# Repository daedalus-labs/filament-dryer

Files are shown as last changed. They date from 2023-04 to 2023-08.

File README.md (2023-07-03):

# MQTT Filament Dryer

This project is Raspberry Pi Pico-based dryer for Filament for use with 3D Printers that provides feedback and command/control through MQTT.

This project does not have any external dependencies, but does require the [Pico C/C++ SDK](https://www.raspberrypi.com/documentation/microcontrollers/c_sdk.html#sdk-setup)
to build. The [picotool](https://github.com/raspberrypi/picotool) project is required for installing configuration data.

## Build

In order to build, the `PICO_SDK_PATH` environment variable must be set. Once that is set, the `build.bash` script provides
a single command build interface, which will build using all default build options:

```bash
./build.bash --build
```

The `build.bash` script will forward CMake args, so build options can be modified using `-D{OPTION}={VALUE}`. For
example, the command below will build this project with such that the temperature sensor will read data from `GP12`.

```bash
./build.bash --build -DDHT_DATA_PIN=12
```

### Available Build Options

| Option | Default Value | Description |
| --- | --- | --- |
| MQTT_PORT | 1883 | The TCP/IP Port to use for MQTT communication |
| DHT_FEEDBACK_PIN | 254 | The GPIO pin of the DHT Feedback LED. The LED will be `ON` when reading data, `OFF` otherwise |
| DHT_DATA_PIN | 17 | The GPIO pin of the DHT Temperature Sensor. |
| HEATER_FEEDBACK_PIN | 15 | The GPIO pin of the Heater Feedback LED. It is `ON` when the heater is on, `OFF` otherwise |
| HEATER_CONTROL_PIN  | 19 | The GPIO pin of the Heater Relay. |
| SYSTEM_LED_PIN | 13 | The GPIO pin of the System LED. It is `ON` when the Pico has booted and is running, `OFF` otherwise  |
| MQTT_FEEDBACK_PIN | 14 | The GPIO pin of the MQTT Feedback LED. It is `ON` when connected to the MQTT broker, `OFF` otherwise |

The LED behaviors of `DHT_FEEDBACK_PIN`, `SYSTEM_LED_PIN`, `MQTT_FEEDBACK_PIN`, and `HEATER_FEEDBACK_PIN` can all be disabled by setting that value
to a value larger than `NUM_BANK0_GPIOS`. A default value of `254` means that LED is not used by default.

### Cleaning

The `build.bash` script also provides an option to clean out all build artifacts via `--clean`:

```bash
./build.bash --clean
```

## Installation

After building the project, the `filament-dryer.uf2` file can be copied to the Pico as described in the [fine manuals for the Pico](https://www.raspberrypi.com/documentation/microcontrollers/c_sdk.html#your-first-binaries).

Additional documentation on wiring setup and a pre-designed enclosure is available [here](docs/README.md).

### Configuration

Configuration data is loaded onto the Raspberry Pi at run-time using the `load.py` script, which will encode the data into
a binary blob and load in the Pico's flash. The Pico should be hooked up to the computer before running the script.

```bash
./load.py --ssid MyAwesomeWifi --passphrase DontHackMyNetwork --device daryl --broker wilson
```

| Option | Description |
| --- | --- |
| `--ssid` or `-s` | The SSID of the Wireless Network to use for MQTT communication |
| `--passphrase` or `-p` | The passphrase of the Wireless network |
| `--device` or `-d` | The device name to use for MQTT communication |
| `--broker` or `-b` | The hostname or IP address of the MQTT Broker to use |

### Monitoring via MQTT

The dryer publishes a collection fo MQTT topics for monitoring the status of the dryer. All topics are relative
to the device name (i.e. if the device is named `daryl`, the container humidity will be available on `daryl/container/humidity`).

| Topic | Description | Data Type |
| --- | --- | --- |
| `container/humidity` | The current humidity within the container, as a percentage. | Float |
| `container/temperature` | The current temperature within the container, in degrees Celsius. | Float |
| `container/target_temperature` | The desired temperature within the container, in degrees Celsius. | Float |
| `container/heater` | The current state of the heater. Will be "on" if it is on, "off" otherwise. | String |

The dryer subscribes to the following MQTT topics for command/control of the dryer:

| Topic | Description | Data Type |
| --- | --- | --- |
| `container/target_temperature/set` | Sets the desired temperature within the container, in degrees Celsius. | Float |

Finally, there are some MQTT topics that provide metadata on the device status:

| Topic | Description | Data Type |
| --- | --- | --- |
| `board/temperature` | The current temperature of the Pico, in degrees Celsius. | Float |
| `version` | The version of software running on the Pico. | String |
| `uid` | The UID of the Pico. | String |

It should be noted that the MQTT interface will require all data be encoded as a string; the `Data Type` column above

## Credits and Thanks

* [Hermann-SW](https://gist.github.com/Hermann-SW) for sharing guides on how to use the Raspberry Pi Pico's flash memory on the [Raspberry Pi Forums](https://forums.raspberrypi.com//viewtopic.php?f=145&t=300146).
* [Erich Styger](https://github.com/ErichStyger) for a really great breakdown of using [MQTT in the lwIP stack](https://mcuoneclipse.com/2023/02/11/using-mqtt-with-the-raspberry-pi-pico-w-and-homeassistant-for-an-optimized-solar-energy-electrical-vehicle-charger/).

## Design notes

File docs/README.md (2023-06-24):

# Building the Filament Dryer

This project will make use of an existing dryer box. [This one](https://www.thingiverse.com/thing:2953325) is recommended, but
any dryer box that can support a heater and temperature sensor will work.

## Necessary Hardware

Once the dryer box is assembled, the following hardware is needed to assembly the controller:

* A [Raspberry Pi Pico W or WH](https://www.raspberrypi.com/products/raspberry-pi-pico/?variant=raspberry-pi-pico-w).
* A prototype PCB large enough to support the Pico.
  * The enclosure was designed around the [ElectroCookie Prototype PCB](https://www.amazon.com/dp/B07ZYNWJ1S).
* A 5V Relay capable of supporting the Heater.
  * The enclosure was designed around this [HiLetgo](https://www.amazon.com/dp/B00LW15A4W) relay.
* An AC-to-DC Power Module capable of providing 5V at 1A or greater.
  * The enclosure was designed around this [NOYITO](https://www.amazon.com/dp/B07C1XCH68) power module.
* A DHT-22/AM-2302 Temperature sensor.
  * [HiLetgo](https://www.amazon.com/dp/B0795F19W6) offers one already wired and ready to go.
* A heating pad for a terrarium or reptile enclosure.
  * This one from [BN-LINK](https://www.amazon.com/dp/B08C93ZGPJ) is a cheap and effective option.
* A desiccant for drying the air.
  * [Slice Engineering](https://www.amazon.com/dp/B09BVYYD7B) makes one specifically for filament.

Assembly will also require basic electrical components, such as wires, LEDs, resistors, diodes, header pins, solder, and
[splicing connectors](https://www.amazon.com/dp/B08W3QXN9B), as well as [grommets](https://www.amazon.com/dp/B09MT34X2B)
to help seal the holes drilled in the enclosure.

## Wiring and Assembly

Most of the components, such as the relay and power module, will be ready to go out of the box and need only be
dropped into the enclosure and wired to the Pico PCB. They can be set aside until the Pico PCB is ready.

### Setting up the Pico PCB

Although any PCB software can be used to create a custom PCB, the wiring here is simple enough that using a Prototyping
PCB is fairly straight forward. Simply solder on headers as shown below:

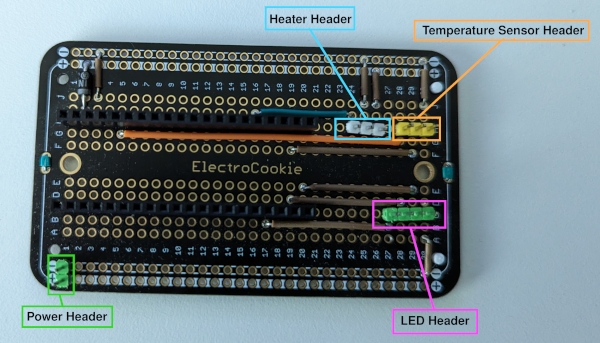
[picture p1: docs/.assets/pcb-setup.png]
Header Diagram


If using the default build options, the headers will be wired as shown in [this diagram](.assets/pcb.png). The setup
used here powers the Pico through VSYS, which requires a schottky diode (D1), a 1N5817 in the linked diagram, in order
to protect the system when using a USB to monitor or reprogram the device.

Once all the headers are soldered in place, the Pico PCB should look something like this:

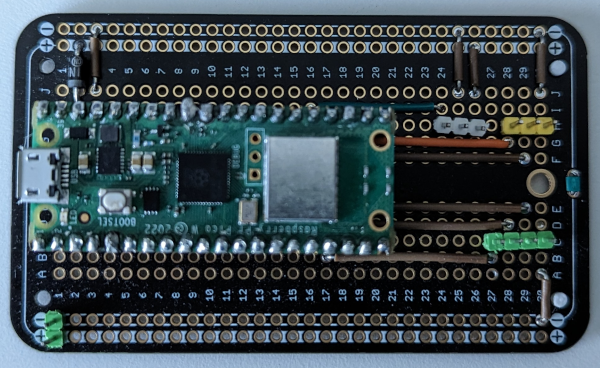
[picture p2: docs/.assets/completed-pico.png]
Pico PCB


It is possible to use a different setup if it is not possible to get a Pico WH or solder on headers, as long as the
connections match the provided wiring diagram (or whatever the build options specify).

### Enclosure

The enclosure comes in two pieces: The enclosure base and a lid. The STL files are available in the `stl` folder, and can
be imported into something like [Cura](https://ultimaker.com/software/ultimaker-cura/) or [Slic3r](https://slic3r.org/)
for use with 3D Printers.

It has been designed with the intention of not requiring supports to print, with a lid that allows easy access to the internal
components should anything need to be updated in the future. This is a filament dryer, so the goal of the lid is primarily
to prevent incidental contact with the internal parts.

The sensor and heater can come in through the large hole in the front of the enclosure, which can optionally be sealed with
a grommet if desired. There is also 3 small holes up front designed for 5mm LEDs, which by default are used to indicate when
the Heater is on/off, MQTT is connected, and the system is on.

Once the enclosure has been printed and the Pico PCB assembled, the components should all drop in:

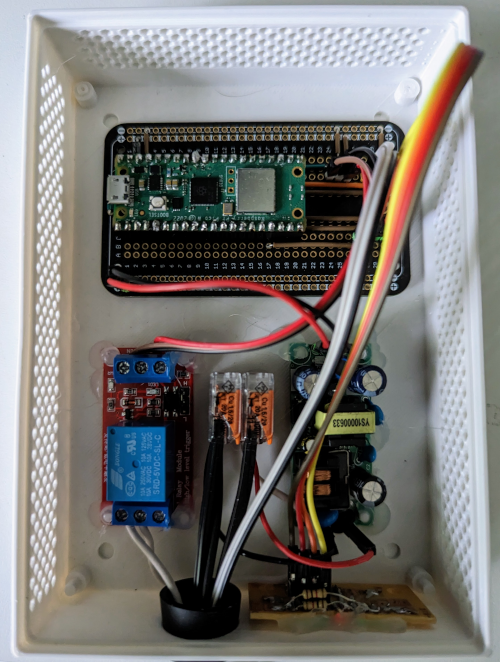
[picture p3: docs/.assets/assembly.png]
Full Assembly


#### Modifying the Enclosure

The CAD models for the enclosure are provided in the `cad` folder. They can be modified using [FreeCAD](https://www.freecad.org/).

### Connecting the Heater

Connecting the Heater only requires cutting off the AC plug it comes with and connecting it to the Power Relay using the
splicing connecters as shown below:

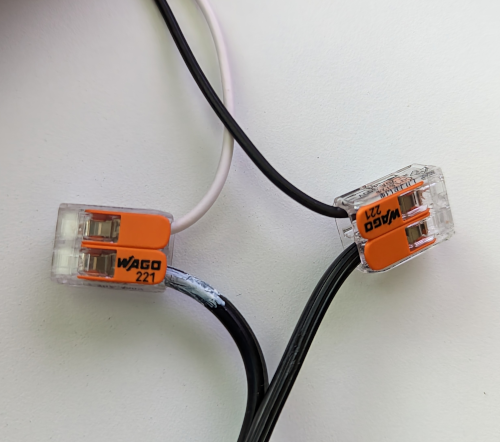
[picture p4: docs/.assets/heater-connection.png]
Heater Connecting


### Putting it all together

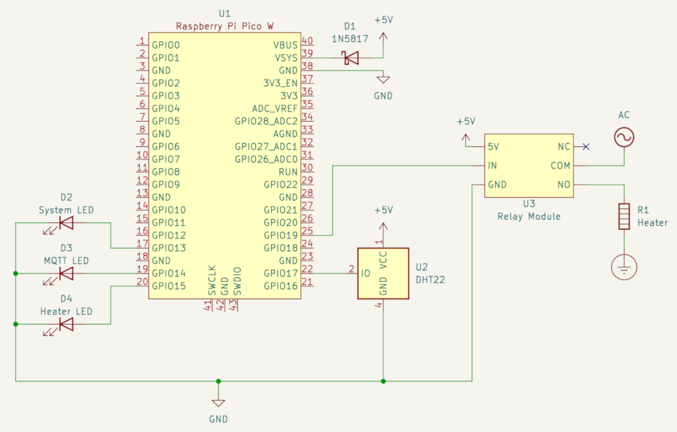
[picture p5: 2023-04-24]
docs/.assets/pcb.png

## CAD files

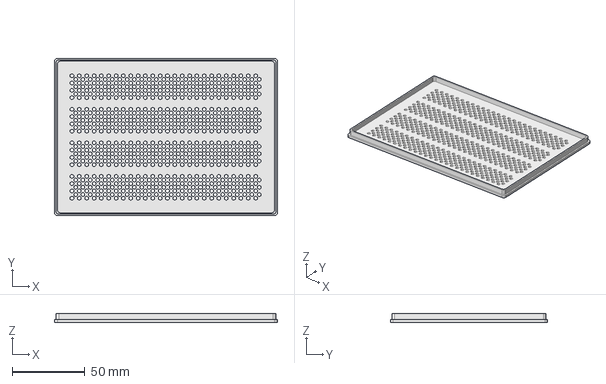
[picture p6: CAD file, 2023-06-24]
docs/cad/enclosure-lid-no-pegs.FCStd
153.0 x 108.0 x 6.00 mm

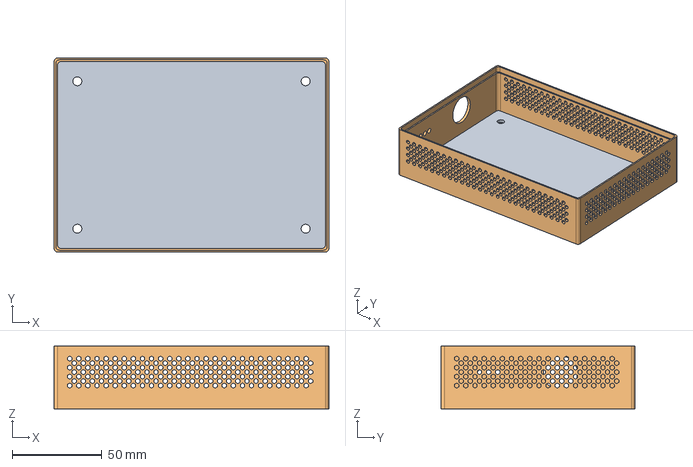
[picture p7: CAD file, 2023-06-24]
docs/cad/enclosure-no-pegs.FCStd
153.0 x 108.0 x 35.0 mm
Enclosure Base
Enclosure Walls

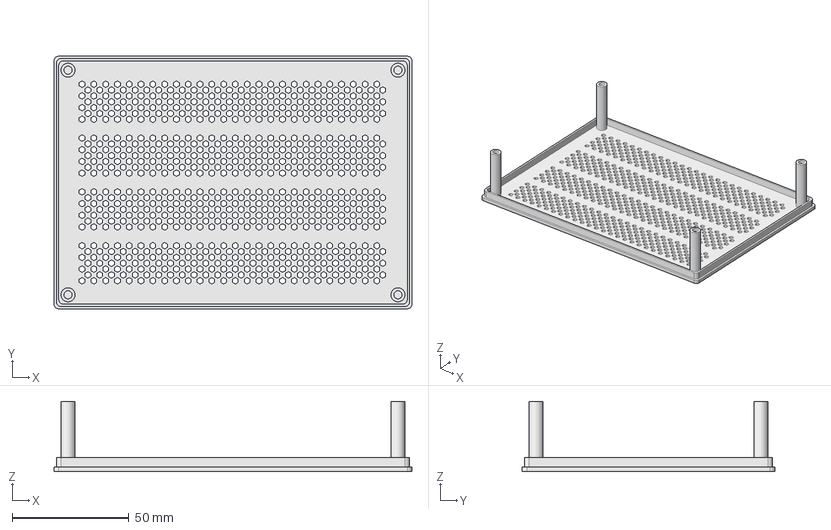
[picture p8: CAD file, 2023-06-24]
docs/cad/enclosure-lid.FCStd
153.0 x 108.0 x 30.0 mm

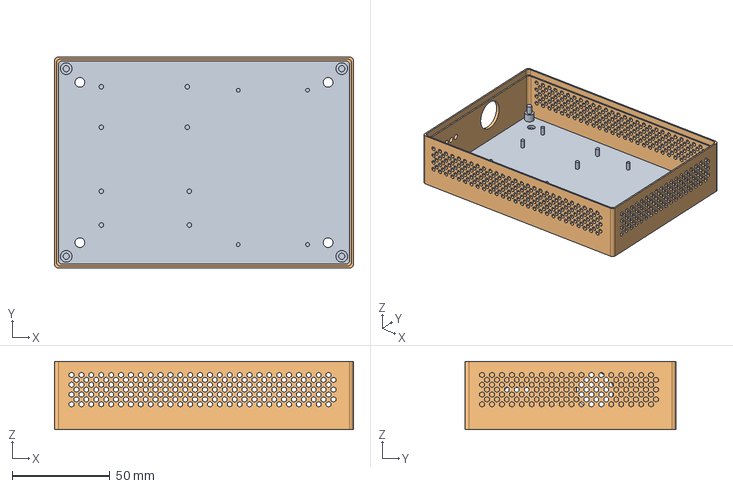
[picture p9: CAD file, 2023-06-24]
docs/cad/enclosure.FCStd
153.0 x 108.0 x 35.0 mm
Enclosure Base
Enclosure Walls

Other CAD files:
docs/stl/enclosure-lid-no-pegs.stl
docs/stl/enclosure-lid.stl
docs/stl/enclosure-no-pegs.stl
docs/stl/enclosure.stl

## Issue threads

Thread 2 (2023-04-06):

Import sensors library from environment monitor

jporembski, 2023-04-06:
This issue covers pulling in the sensors library from daedalus-labs/environment-monitor

Closed 2023-04-06.

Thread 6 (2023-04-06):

Add heater controller

jporembski, 2023-04-06:
This issue covers the integration of a class (or classes) to control the heating
element based on feedback from the DHT sensor.

Closed 2023-04-24.

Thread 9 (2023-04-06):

Add Fan control

jporembski, 2023-04-06:
The filament dryer will need some kind of enclosure for the pico, relay, and power supply.

It makes sense to include a fan in this enclosure controlled by the pico.

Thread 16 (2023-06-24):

Heater status is invalid

jporembski, 2023-06-24:
Currently, heater status is not showing up correctly in mosquitto.

Since heater status is read-only, it makes sense to be a string.

Closed 2023-07-03.

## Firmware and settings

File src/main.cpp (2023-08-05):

/*------------------------------------------------------------------------------
Copyright (c) 2023 Joe Porembski
SPDX-License-Identifier: BSD-3-Clause
------------------------------------------------------------------------------*/
#include "connectivity/mqtt.hpp"
#include "connectivity/wireless.hpp"
#include "controllers/heater.hpp"
#include "generated/configuration.hpp"
#include "sensors/board.hpp"
#include "sensors/constants.hpp"
#include "sensors/dht.hpp"
#include "utilities.hpp"

#include <hardware/adc.h>
#include <hardware/gpio.h>
#include <pico/multicore.h>
#include <pico/stdio.h>
#include <pico/stdlib.h>
#include <pico/unique_id.h>
#include <pico/util/queue.h>

#include <cerrno>
#include <cstdint>
#include <cstdio>
#include <functional>
#include <string_view>


inline constexpr float HEATER_HYSTERESIS = 2.5f;
inline constexpr uint64_t HEATER_MAX_ON_TIME_MS = 10 * 60 * 1000;
inline constexpr uint32_t DATA_PERIOD_MS = 10000;
inline constexpr uint32_t COMMUNICATION_PERIOD_MS = 10000;
inline constexpr uint32_t MQTT_CONNECTION_WAIT_MS = 17500;
inline constexpr uint8_t QUEUE_SIZE = 5;
inline constexpr uint8_t WIFI_NOT_CONNECTED_THRESHOLD = 6;

typedef struct
{
    float board_temperature;
    float container_temperature;
    float container_humidity;
    float target_temperature;
    bool heater_on;
} feedback_entry;

typedef struct
{
    float target_temperature;
} request_entry;

queue_t feedback_queue;
queue_t request_queue;

void controlLoop()
{
    DHT sensor(DHTType::DHT22, DHT_DATA_PIN, DHT_FEEDBACK_PIN);
    sensors::Board board;
    controllers::Heater heater(HEATER_CONTROL_PIN, HEATER_FEEDBACK_PIN, HEATER_HYSTERESIS, HEATER_MAX_ON_TIME_MS);

    while (true) {
        if (!queue_is_empty(&request_queue)) {
            request_entry request;
            queue_remove_blocking(&request_queue, &request);
            heater.setTargetTemperature(request.target_temperature);
        }

        sensor.read();
        heater.update(sensor.temperature());

        feedback_entry new_data_point;
        new_data_point.board_temperature = board.temperature();
        new_data_point.container_humidity = sensor.humidity();
        new_data_point.container_temperature = sensor.temperature();
        new_data_point.target_temperature = heater.targetTemperature();
        new_data_point.heater_on = heater.isOn();

        queue_add_blocking(&feedback_queue, &new_data_point);
        sleep_ms(DATA_PERIOD_MS);
    }
}

feedback_entry getMostRecentData()
{
    feedback_entry data;
    queue_remove_blocking(&feedback_queue, &data);
    while (!queue_is_empty(&feedback_queue)) {
        queue_remove_blocking(&feedback_queue, &data);
    }
    return data;
}

static void publish(mqtt::Client& client, const feedback_entry& data)
{
    std::string board_temperature = std::to_string(data.board_temperature);
    std::string container_temperature = std::to_string(data.container_temperature);
    std::string container_humidity = std::to_string(data.container_humidity);
    std::string target_temperature = std::to_string(data.target_temperature);

    char mqtt_topic[TOPIC_BUFFER_SIZE];
    snprintf(mqtt_topic, TOPIC_BUFFER_SIZE, BOARD_TEMPERATURE_TOPIC_FORMAT.data(), client.deviceName().c_str());
    mqtt::publish(client, mqtt_topic, board_temperature);

    snprintf(mqtt_topic, TOPIC_BUFFER_SIZE, HUMIDITY_TOPIC_FORMAT.data(), client.deviceName().c_str());
    mqtt::publish(client, mqtt_topic, container_humidity);

    snprintf(mqtt_topic, TOPIC_BUFFER_SIZE, TEMPERATURE_TOPIC_FORMAT.data(), client.deviceName().c_str());
    mqtt::publish(client, mqtt_topic, container_temperature);

    snprintf(mqtt_topic, TOPIC_BUFFER_SIZE, HEATER_TOPIC_FORMAT.data(), client.deviceName().c_str());
    if (data.heater_on) {
        mqtt::publish(client, mqtt_topic, controllers::Heater::STATUS_ON.data());
    }
    else {
        mqtt::publish(client, mqtt_topic, controllers::Heater::STATUS_OFF.data());
    }

    snprintf(mqtt_topic, TOPIC_BUFFER_SIZE, TARGET_TEMPERATURE_TOPIC_FORMAT.data(), client.deviceName().c_str());
    mqtt::publish(client, mqtt_topic, target_temperature);
}

static void initialize()
{
    stdio_init_all();
    adc_init();

    queue_init(&feedback_queue, sizeof(feedback_entry), QUEUE_SIZE);
    queue_init(&request_queue, sizeof(request_entry), QUEUE_SIZE);

    gpio_init(SYSTEM_LED_PIN);
    gpio_set_dir(SYSTEM_LED_PIN, GPIO_OUT);
    gpio_put(SYSTEM_LED_PIN, ON);
}

static void onSetTargetTemperatureReceived(const std::string& topic, const mqtt::Buffer& data)
{
    errno = 0;
    request_entry set_request;
    std::string value = mqtt::toString(data);
    set_request.target_temperature = strtof(value.c_str(), NULL);

    if (errno) {
        printf("Failed to handle %s: %u\n", topic.c_str(), errno);
        return;
    }

    printf("Received request to set target temperature to %.1fC\n", set_request.target_temperature);
    queue_add_blocking(&request_queue, &set_request);
}

static bool initializeMQTT(mqtt::Client& client, const std::string& board_id)
{
    if (!mqtt::initialize(client, board_id)) {
        printf("Failed to initialize MQTT\n");
        return false;
    }

    char mqtt_topic[TOPIC_BUFFER_SIZE];
    snprintf(mqtt_topic, TOPIC_BUFFER_SIZE, SET_TARGET_TEMPERATURE_TOPIC_FORMAT.data(), client.deviceName().c_str());
    if (!client.subscribe(mqtt_topic, onSetTargetTemperatureReceived)) {
        printf("Failed to subscribe to %s\n", mqtt_topic);
        return false;
    }

    printf("Successfully initialized MQTT\n");
    return true;
}

int main(int argc, char** argv)
{
    initialize();
    std::string board_id = systemIdentifier();
    uint32_t count = 0;
    uint32_t wifi_count = 0;
    bool mqtt_initialized = false;

    sleep_ms(5000);
    SystemConfiguration cfg;
    if (!read(cfg)) {
        printf("Failed to read system configuration\n");
        return EXIT_FAILURE;
    }

    WifiConnection wifi(cfg.deviceName(), cfg.ssid(), cfg.passphrase());
    mqtt::Client mqtt(cfg.mqttBroker(), CONFIGURED_MQTT_PORT, cfg.deviceName(), MQTT_FEEDBACK_PIN);
    sleep_ms(COMMUNICATION_PERIOD_MS);

    multicore_launch_core1(controlLoop);

    while (true) {
        if (wifi.status() != ConnectionStatus::CONNECTED) {
            printf("Wifi status: %s\n", toString(wifi.status()).data());
            if (wifi_count > WIFI_NOT_CONNECTED_THRESHOLD) {
                printf("Attempting reconnect of wifi...\n");
                wifi.reset();
                wifi_count = 0;
            }
            else {
                wifi_count++;
            }
            sleep_ms(COMMUNICATION_PERIOD_MS);
            continue;
        }

        if (!mqtt.connected()) {
            printf("Connecting MQTT...\n");
            mqtt_initialized = false;
            mqtt.connect();
            sleep_ms(MQTT_CONNECTION_WAIT_MS);
            continue;
        }

        if (!mqtt_initialized) {
            printf("Initializing MQTT...\n");
            mqtt_initialized = initializeMQTT(mqtt, board_id);
            sleep_ms(COMMUNICATION_PERIOD_MS);
            continue;
        }

        feedback_entry data = getMostRecentData();
        publish(mqtt, data);

        printf("\n----------------- [%u]\n", count);

        wifi.poll();

        printf("Temperature: %.1fC, Humidity: %.1f%%\n", data.container_temperature, data.container_humidity);
        printf("Wifi Connection Status: %s (%s)\n", toString(wifi.status()).data(), wifi.ipAddress().c_str());
        printf("CPU Temperature: %.1fC\n", data.board_temperature);
        printf("MQTT Status: %s\n", mqtt.connected() ? "true" : "false");

        printf("-----------------\n");

        sleep_ms(COMMUNICATION_PERIOD_MS);
        count++;
    }

    return EXIT_SUCCESS;
}

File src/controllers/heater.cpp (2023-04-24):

/*------------------------------------------------------------------------------
Copyright (c) 2023 Joe Porembski
SPDX-License-Identifier: BSD-3-Clause
------------------------------------------------------------------------------*/
#include "controllers/heater.hpp"

#include "constants.hpp"
#include "utilities.hpp"

#include <hardware/gpio.h>
#include <pico/stdio.h>

#include <cstdint>
#include <cstdio>


namespace controllers {
Heater::Heater(uint8_t control_pin, uint8_t feedback_pin, float hysteresis, uint64_t max_on_time)
    : _max_on_time(max_on_time),
      _feedback_pin(feedback_pin),
      _control_pin(control_pin),
      _hysteresis(hysteresis),
      _target_temperature(DEFAULT_TEMPERATURE),
      _on_timepoint(),
      _off_timepoint()
{
    // Hysteresis must be positive in order to prevent the controller from latching into one state.
    if (_hysteresis < MINIMUM_HYSTERESIS) {
        _hysteresis = MINIMUM_HYSTERESIS;
    }

    if (_feedback_pin < NUM_BANK0_GPIOS) {
        gpio_init(_feedback_pin);
        gpio_set_dir(_feedback_pin, GPIO_OUT);
        gpio_put(_feedback_pin, LOW);
    }

    gpio_init(_control_pin);
    gpio_set_dir(_control_pin, GPIO_OUT);
}

bool Heater::isOn() const
{
    return gpio_get(_control_pin);
}

float Heater::targetTemperature() const
{
    return _target_temperature;
}

void Heater::setTargetTemperature(float target_temperature)
{
    if (target_temperature < MINIMUM_TARGET_TEMPERATURE) {
        printf("Target temperature of %.1fC must be greater than %.1fC\n", target_temperature, MINIMUM_TARGET_TEMPERATURE);
        return;
    }

    if (_target_temperature == target_temperature) {
        printf("Heater already has target temperature of %.1fC\n", target_temperature);
        return;
    }

    printf("Heater has new target temperature of %.1fC\n", target_temperature);
    _target_temperature = target_temperature;
}

void Heater::update(float actual_temperature)
{
    float off_threshold = _target_temperature + _hysteresis;
    float on_threshold = _target_temperature - _hysteresis;
    bool is_on = isOn();
    uint64_t current_timepoint = milliseconds();

    if (is_on && ((actual_temperature > off_threshold) || (current_timepoint - _on_timepoint > _max_on_time))) {
        _off();
    }
    else if (!is_on && (actual_temperature < on_threshold)) {
        _on();
    }
}

void Heater::_off()
{
    _off_timepoint = milliseconds();

    printf("Turning off Heater...\n");
    gpio_put(_control_pin, OFF);

    if (_feedback_pin < NUM_BANK0_GPIOS) {
        gpio_put(_feedback_pin, OFF);
    }
}

void Heater::_on()
{
    uint64_t current_timepoint = milliseconds();
    if (current_timepoint - _off_timepoint < MINIMUM_OFF_TIME_MS) {
        printf("Cannot enable heater, has not been off for %u milliseconds\n", MINIMUM_OFF_TIME_MS);
        return;
    }

    printf("Turning on Heater...\n");
    _on_timepoint = current_timepoint;
    gpio_put(_control_pin, ON);

    if (_feedback_pin < NUM_BANK0_GPIOS) {
        gpio_put(_feedback_pin, ON);
    }
}
} // namespace controllers

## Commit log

2023-04-06 Import sensors (#4)
    This commit pulls in the DHT and board sensor classes from the
    daedalus-labs/environment-monitor project.
    Closes #2
2023-04-24 Add PCB diagram
    [dryer-schematic.kicad_sch]
2023-04-24 Add Heater Controller (#10)
    This commit adds the `controllers::Heater` class, as well
    as several cosmetic changes to the MQTT stack and updates
    to the LED feedback assignments.
    Closes #6
2023-05-15 Add MQTT communication (#11)
    This commit adds all the expected MQTT topics for both publishing
    and subscribing. All topics are relative to the device name as follows:
    Published Topics:
    * `board/temperature`: The current temperature of the Pico.
    * `container/humidity`: The current humidity of the container.
    * `container/temperature`: The current temperature of the container.
    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
2023-06-02 Enable configuration data to be read from flash (#13)
    This commit adds the ability for configuration data to be read from the
    pico's flash memory at start-up rather than requiring it to be compile
    time constants.
    This is handled through using pointer constants based on the logic
    outlined here: https://forums.raspberrypi.com//viewtopic.php?f=145&t=300146.
    Additionally, this commit adds a python script to load the configuration
    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
2023-06-24 Add supporting documentation (#15)
    This commit adds READMEs for both the project and the product.
    Closes #8
    [enclosure-lid-no-pegs.FCStd, enclosure-lid-no-pegs.stl, enclosure-lid.FCStd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]
2023-07-03 Update heater status value (#17)
    This commit changes the value of `container/heater` from an integer
    to a string.
    Closes #16
2023-07-03 Fix build issues (#18)
    This commit addresses the build issues introduced with #17
    [main.cpp]
2023-08-05 Improve wireless capabilities (#19)
    This commit updates the implementation of Wifi to support
    the ability to set a `hostname` for a device. By default, this
    will be the MQTT device name for simplicity; however, the
    `WifiConnection` class will accept any string.
    Additionally, this commit fixes a minor bug noticed after
    power outages wherein the pico and networking hardware
    come up at close to the same time, resulting in the pico
    needing to be rebooted. This is addressed by adding the
    ability to `reset` the wireless connection.
    [main.cpp]
